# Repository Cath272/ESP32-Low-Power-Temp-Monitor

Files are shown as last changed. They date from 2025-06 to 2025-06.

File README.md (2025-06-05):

# ESP32 Low Power Temp Monitor

## Introduction
ESP32 Low Power Temp Monitor is an ESP32 C6 based low power Temperature and Humidity Monitor that aims to have a device that is very efficent and doen't need charging.
## General description
The device reads the temperature, relative humidity and barometric pressure  and displays it on an 4.2 inch Epaper Display, alonside the current date and time.
The device is awake just for a few seconds as it reads the tempereature and displays it and then goes to sleep. It performs a reading every minute.
One a day it connects to WiFi and checks the current time to sync up with an NTP server to account for Daylight saving time and potential drifts in the internal esp32 real time clock.

In the project files you may find ESP32-C3 instead of ESP32-C6. I named it wrong when i created the project. The issue is just the file names, the footprints are correct and use a C6.
The TPL5111 is currenly does not work properly so i emulated it in software using the esp32 deep sleep.

### Block diagram
block diagram

## Hardware Design
### ESP32 C6 Wroom 1 Module
This project is based around a ESP32 C6 Wroom 1 Module that incorporates a RISC-V single-core microprocessor with 4MB of flash, WiFi 6 and Zigbee
### TPS63020
The TPS63020 is High Efficiency Single Inductor Buck-Boost Converter, used for  converting the 5v from usb or the Li-ion battery voltage(3.0v to 4.2v) to a very stable 3.3V for the Microcontroller and the epaper display. The main advantage of this ic is its low operating quiescent current: 25 μA; and it's low cost:0.55€
### BME280
The BME280 is a digital humidity, pressure and temperature sensor.
### 4.2 Inch Epaper Display 
GDEY042Z98 Tri color (Black, White and Red) Epaper display using a SSD1683 driver chip, the main benefit of this display is its big size (4.2 inch) and very good price for an Epaper display (around 10€)
### TPL5111
The TPL5111 is a Nano Power System timer for power gating. It is used to turn on the esp32 every minute to read the temperature
### MCP7381
The MCP7381 is an integrated Li-ion cell battery controller 
### Li-ion 250MAh battery
Small 250Mah generic Li-ion cell with protection, used because of its small size
### Solar Panel
Generic 1W 5V Solar panel 

## Schematic
[Schematic](PCB/ESP32%20%20C3%20Zigbee%20Temp/ESP32%20%20C3%20Zigbee%20Temp.pdf)
## Bill of Materials

| Component | Image | Model  | Pcs | Price | 
| --- | ---  | ---  | --- | --- |
| ESP32-C6-WROOM-1-N8  |  Esp32 c6 | ESP32-C6-WROOM-1-N8 | 1 | € 4.91 |
|Buck Boost Coverter  |  | TPS63020 | 1 | € 0.52 | 
| TPL5111 | images | TPL5111 | 1 | € 0.47 | 
| BME280 | images | BME280 | 1 | € 2.78 |
| MCP7381 | images | MCP7381 | 1 | € 0.84 |
| Solar Panel | images | 5V 1W Solar Panel | 1 | € 2.23 |
| 4.2 Inch Epaper Display | images | GDEY042Z98 | 1 | € 11.64 |

## PCB

front_3d
front

## Case and 3d design

The case was make using autocad and exported to stl
The stl files can be found in the 3D Parts folder

The gerber production zip file can be found in the Production folder
## Software Design

The device wakes up, connect to wifi on the first boot, reads the time from an NTP server, and then for the next 24 hours it just reads the temperature and displays it. The time is kept in a register while the esp sleeps and increments it on every boot. Every 24 hours it connect to Wifi to check the time again for accuracy.
The program can be found in the Project_Code folder

### Display
The program is based around the [GxEPD2](https://github.com/ZinggJM/GxEPD2) libary for interfacing with the Epaper display,   

### Fonts
The font used in this project is Roboto with 2 diffrent font sizes: 16pt for the time, date, altitude and barometric pressure and 48pt for the Temeprature and relative humidity
The font were converted from True Type to Adafruit's GFX Font format (also used by GxEPD2 as it is based on Adafruit GFX) using the [ttf2gfx utility](https://github.com/Pconti31/TTF2GFX)

### BME280
Adafruit_BME280 for the BME280 sensor
### Time 
For time i used 4 libraries: 
- esp_timer (esp_idf library) to get the execution time of the code 
- [ESP32Time](https://github.com/fbiego/ESP32Time) for keeeping the time and displaying it in a C style format on the display
- [ezTime](https://github.com/ropg/ezTime) for getting the time from an NTP server, the time is region based in this library and i used it to avoid the problem of keeping track of daylight savings

## Results



## Resources
- [ESP32Time](https://github.com/fbiego/ESP32Time)
- [ttf2gfx utility](https://github.com/Pconti31/TTF2GFX)
- [ezTime](https://github.com/ropg/ezTime)
- [GxEPD2](https://github.com/ZinggJM/GxEPD2)

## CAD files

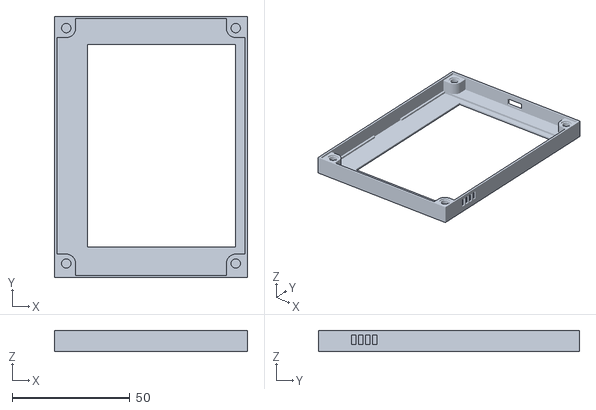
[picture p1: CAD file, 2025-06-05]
3dParts/front32.stl
82.0 x 111.0 x 9.00

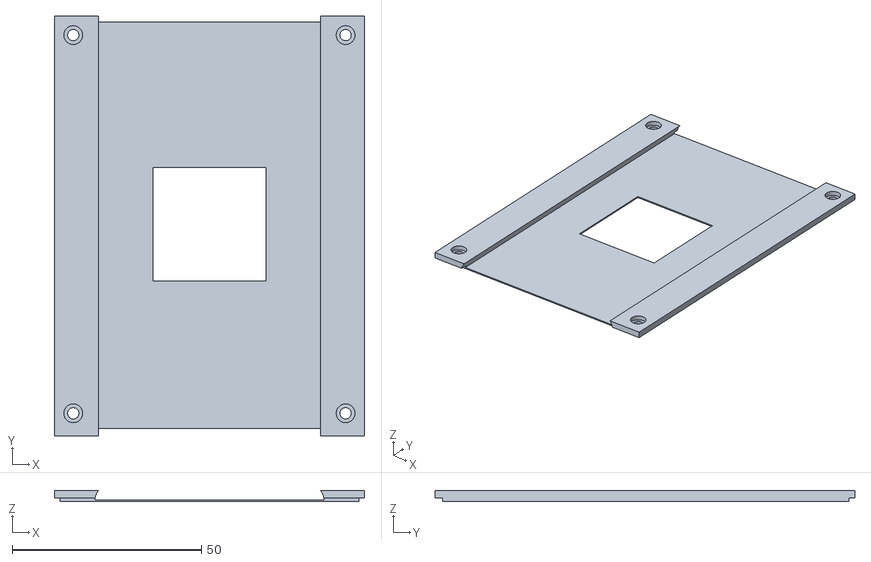
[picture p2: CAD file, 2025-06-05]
3dParts/back32.stl
82.0 x 111.0 x 3.00

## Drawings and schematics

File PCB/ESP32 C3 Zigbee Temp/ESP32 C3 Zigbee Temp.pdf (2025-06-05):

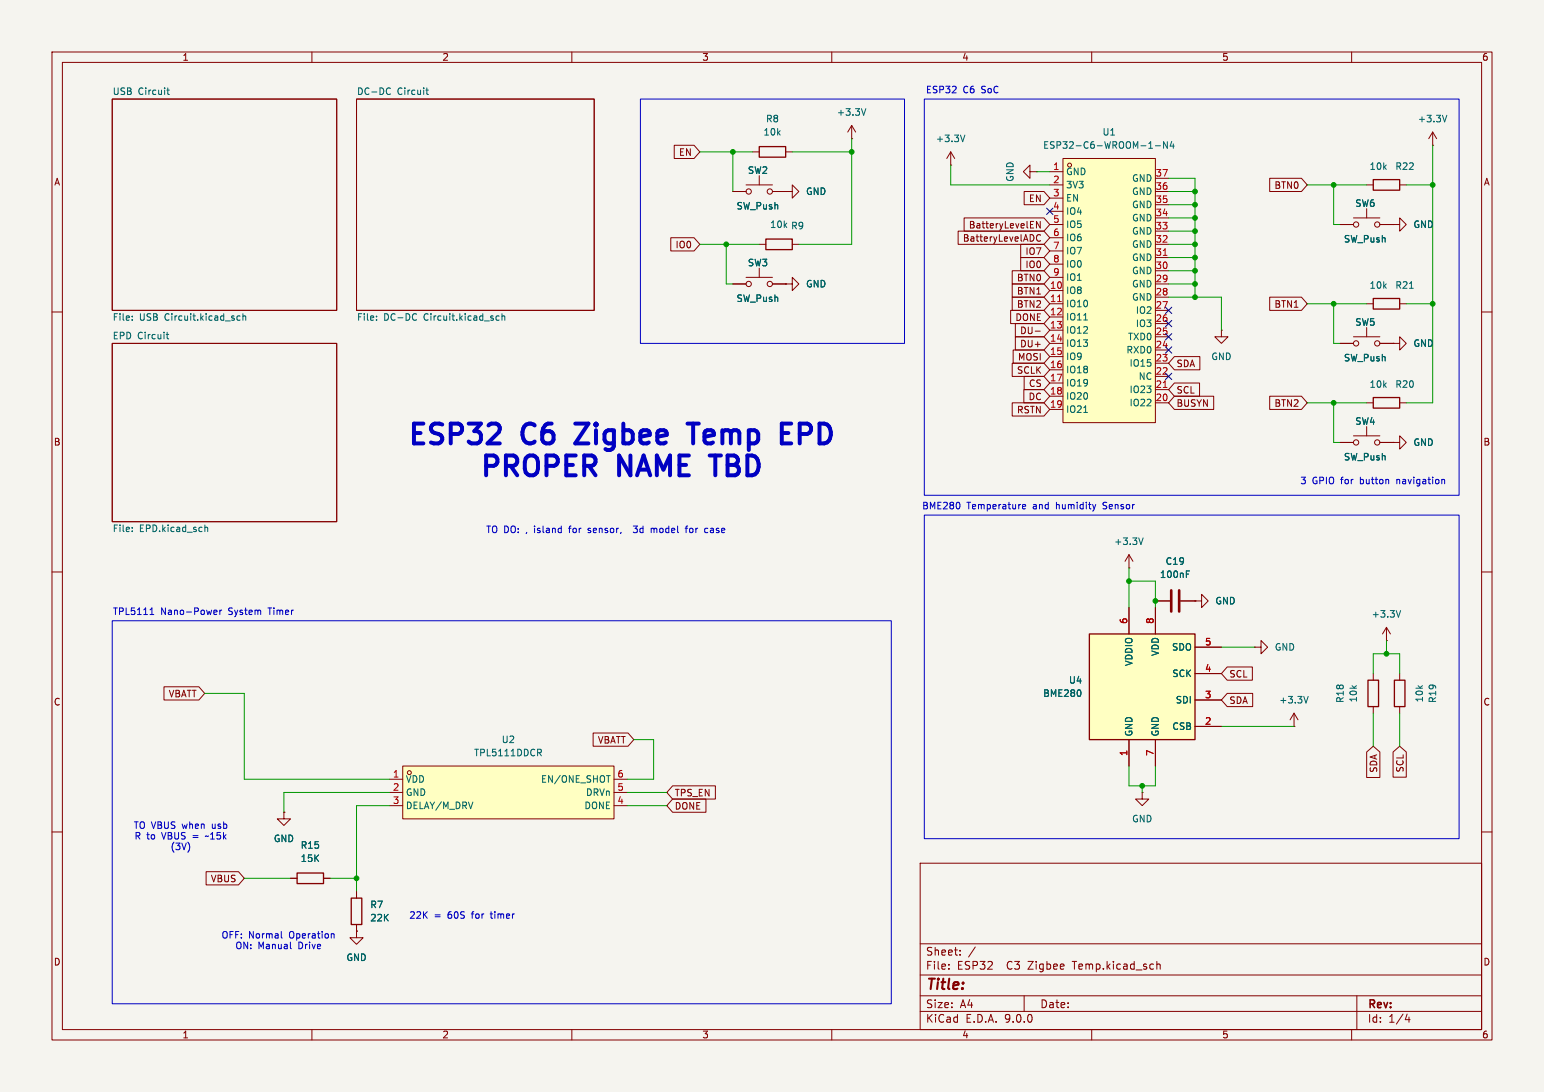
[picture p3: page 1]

7 SDO 5 SCK 4 SDI 3 CSB 2 U4 BME280 +3.3V GND GND

7 SDO 5 SCK 4 SDI 3 CSB 2 C19

OFF: Normal Operation ON: Manual Drive

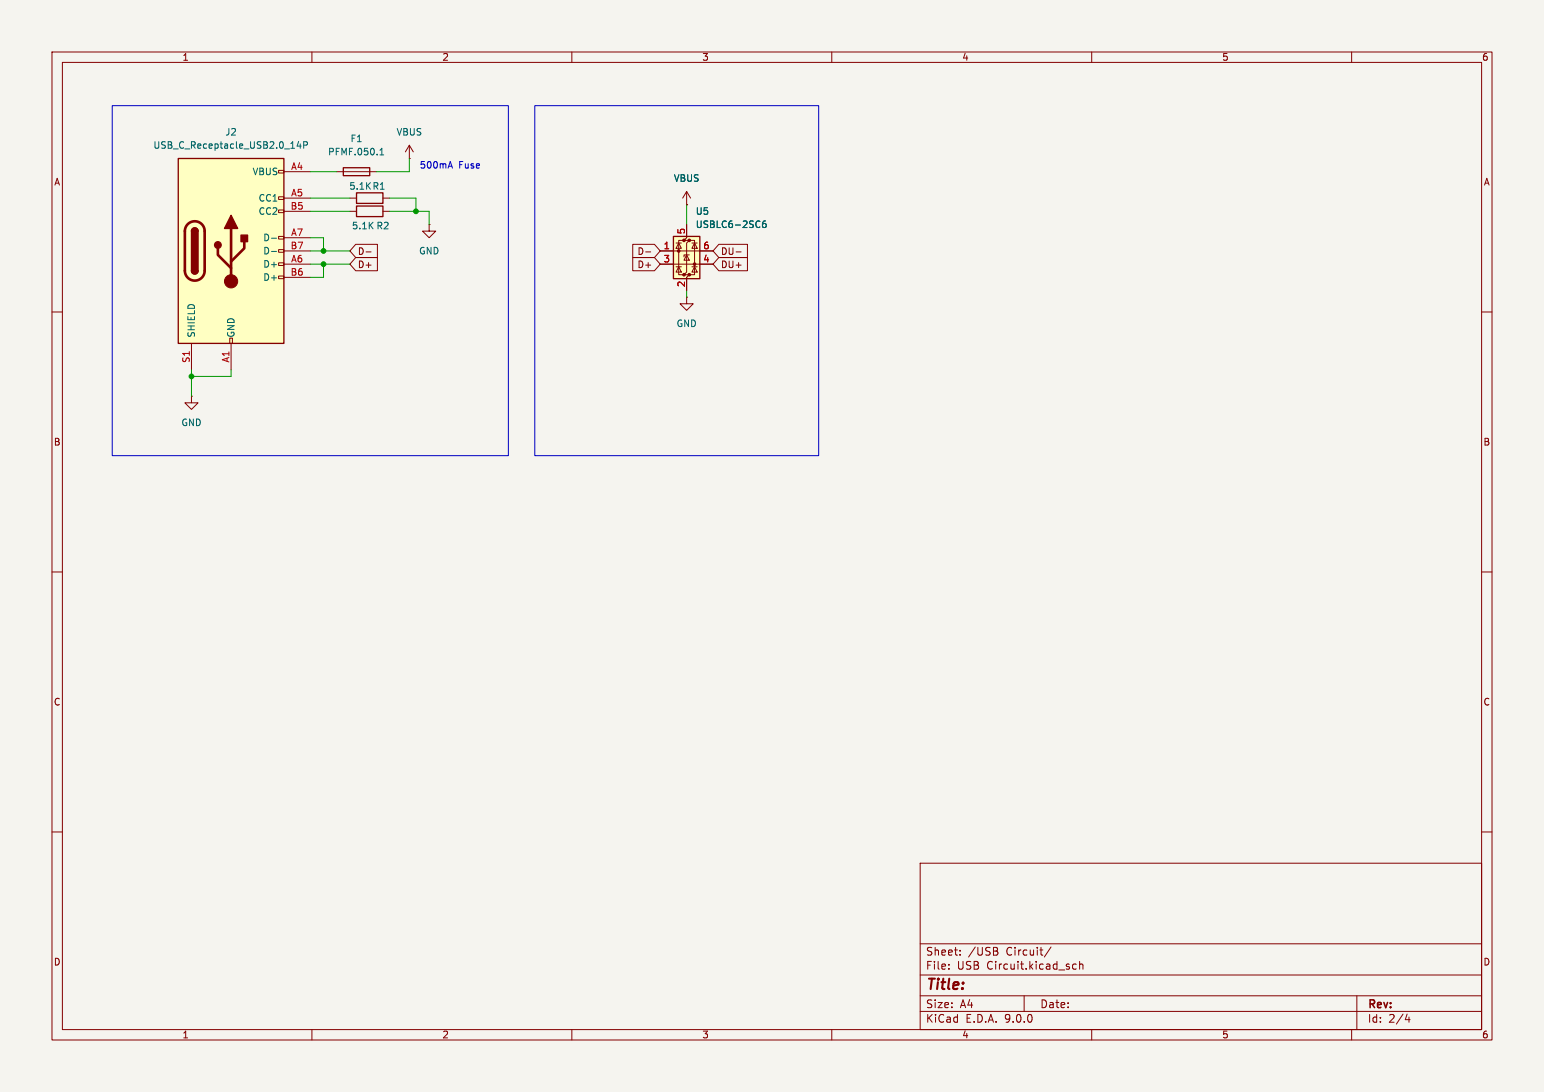
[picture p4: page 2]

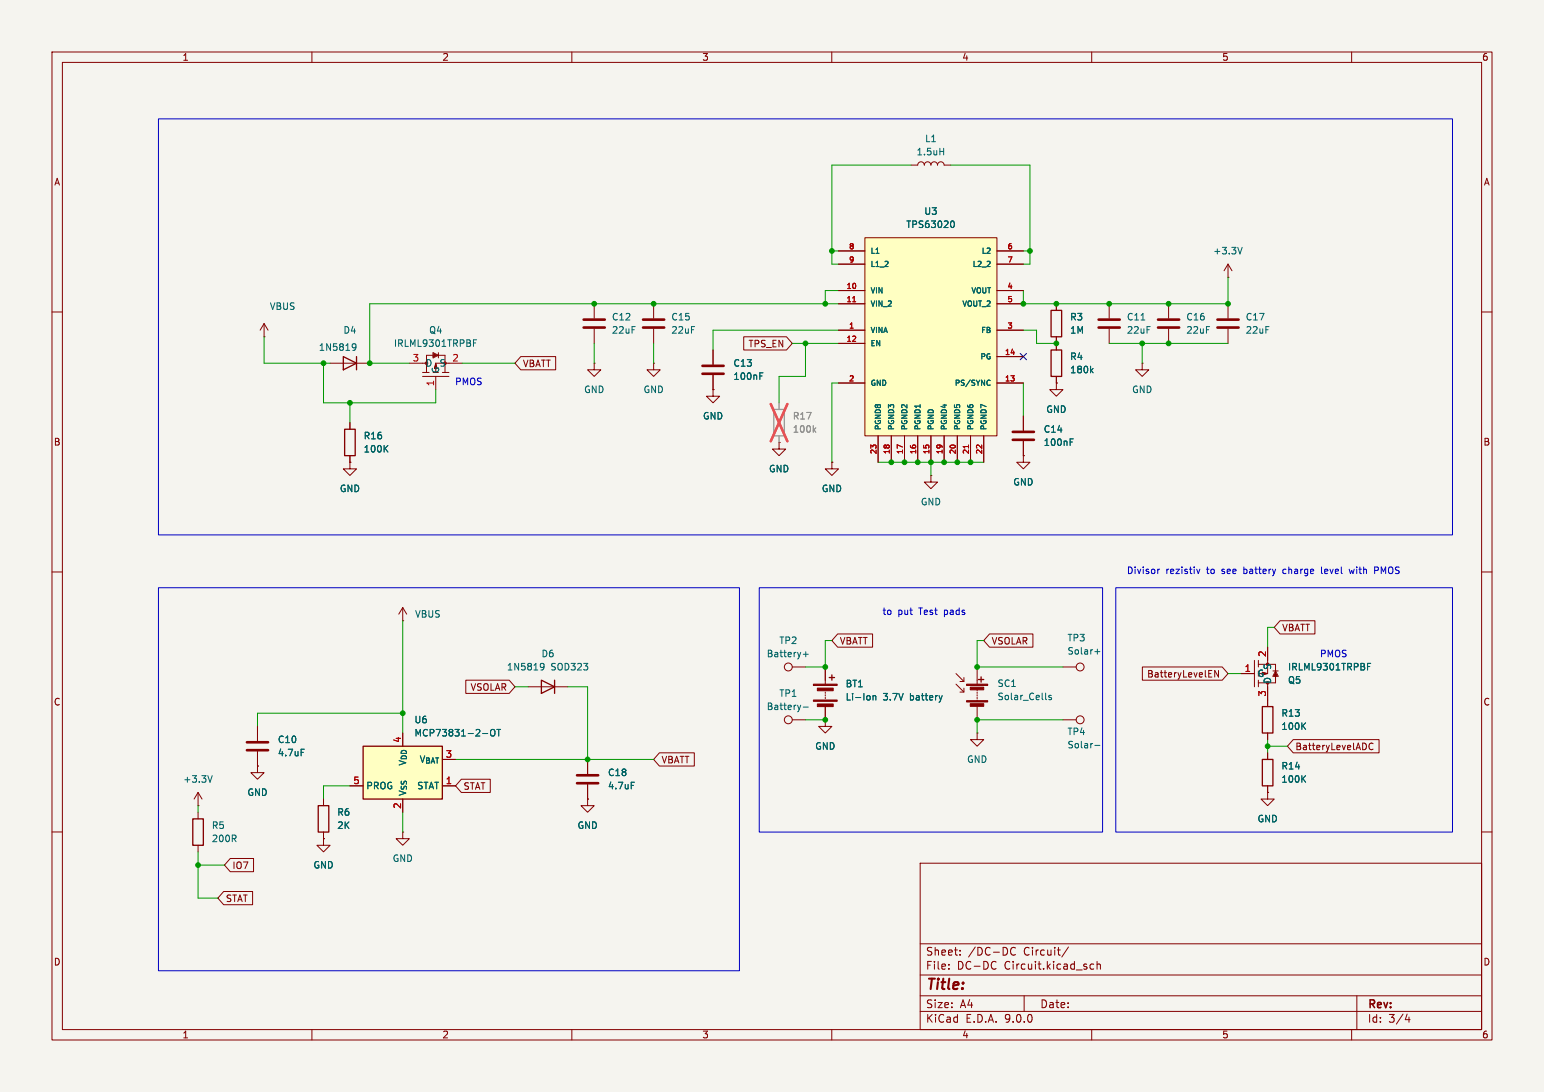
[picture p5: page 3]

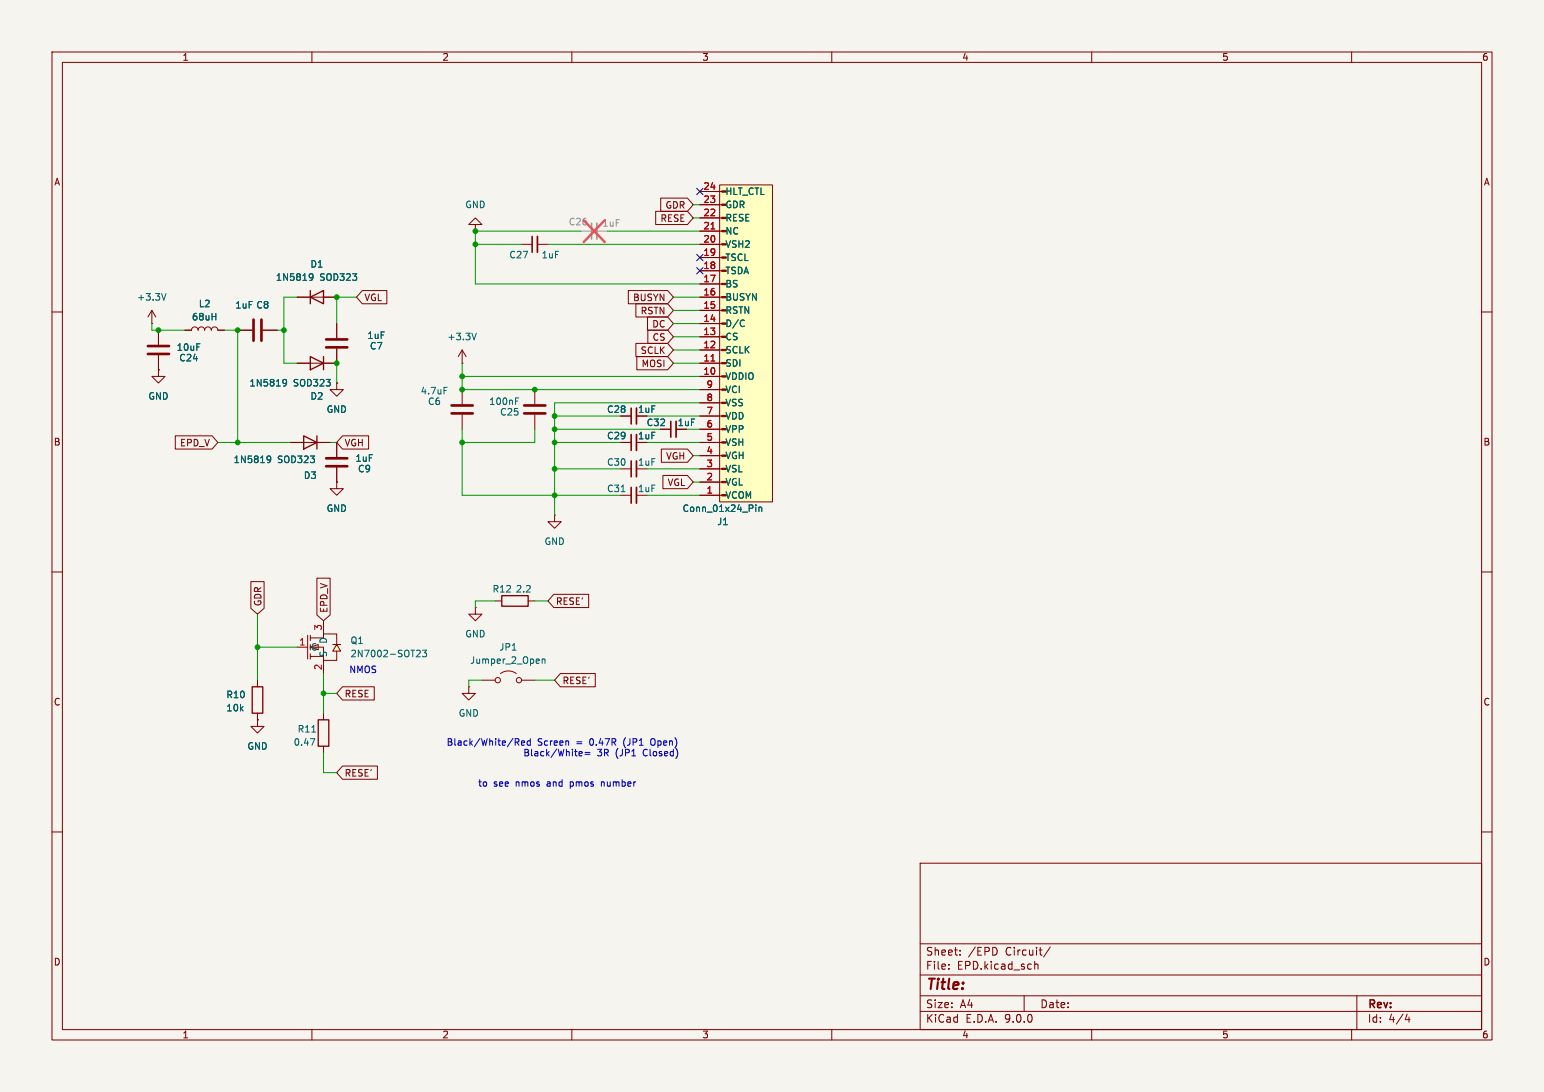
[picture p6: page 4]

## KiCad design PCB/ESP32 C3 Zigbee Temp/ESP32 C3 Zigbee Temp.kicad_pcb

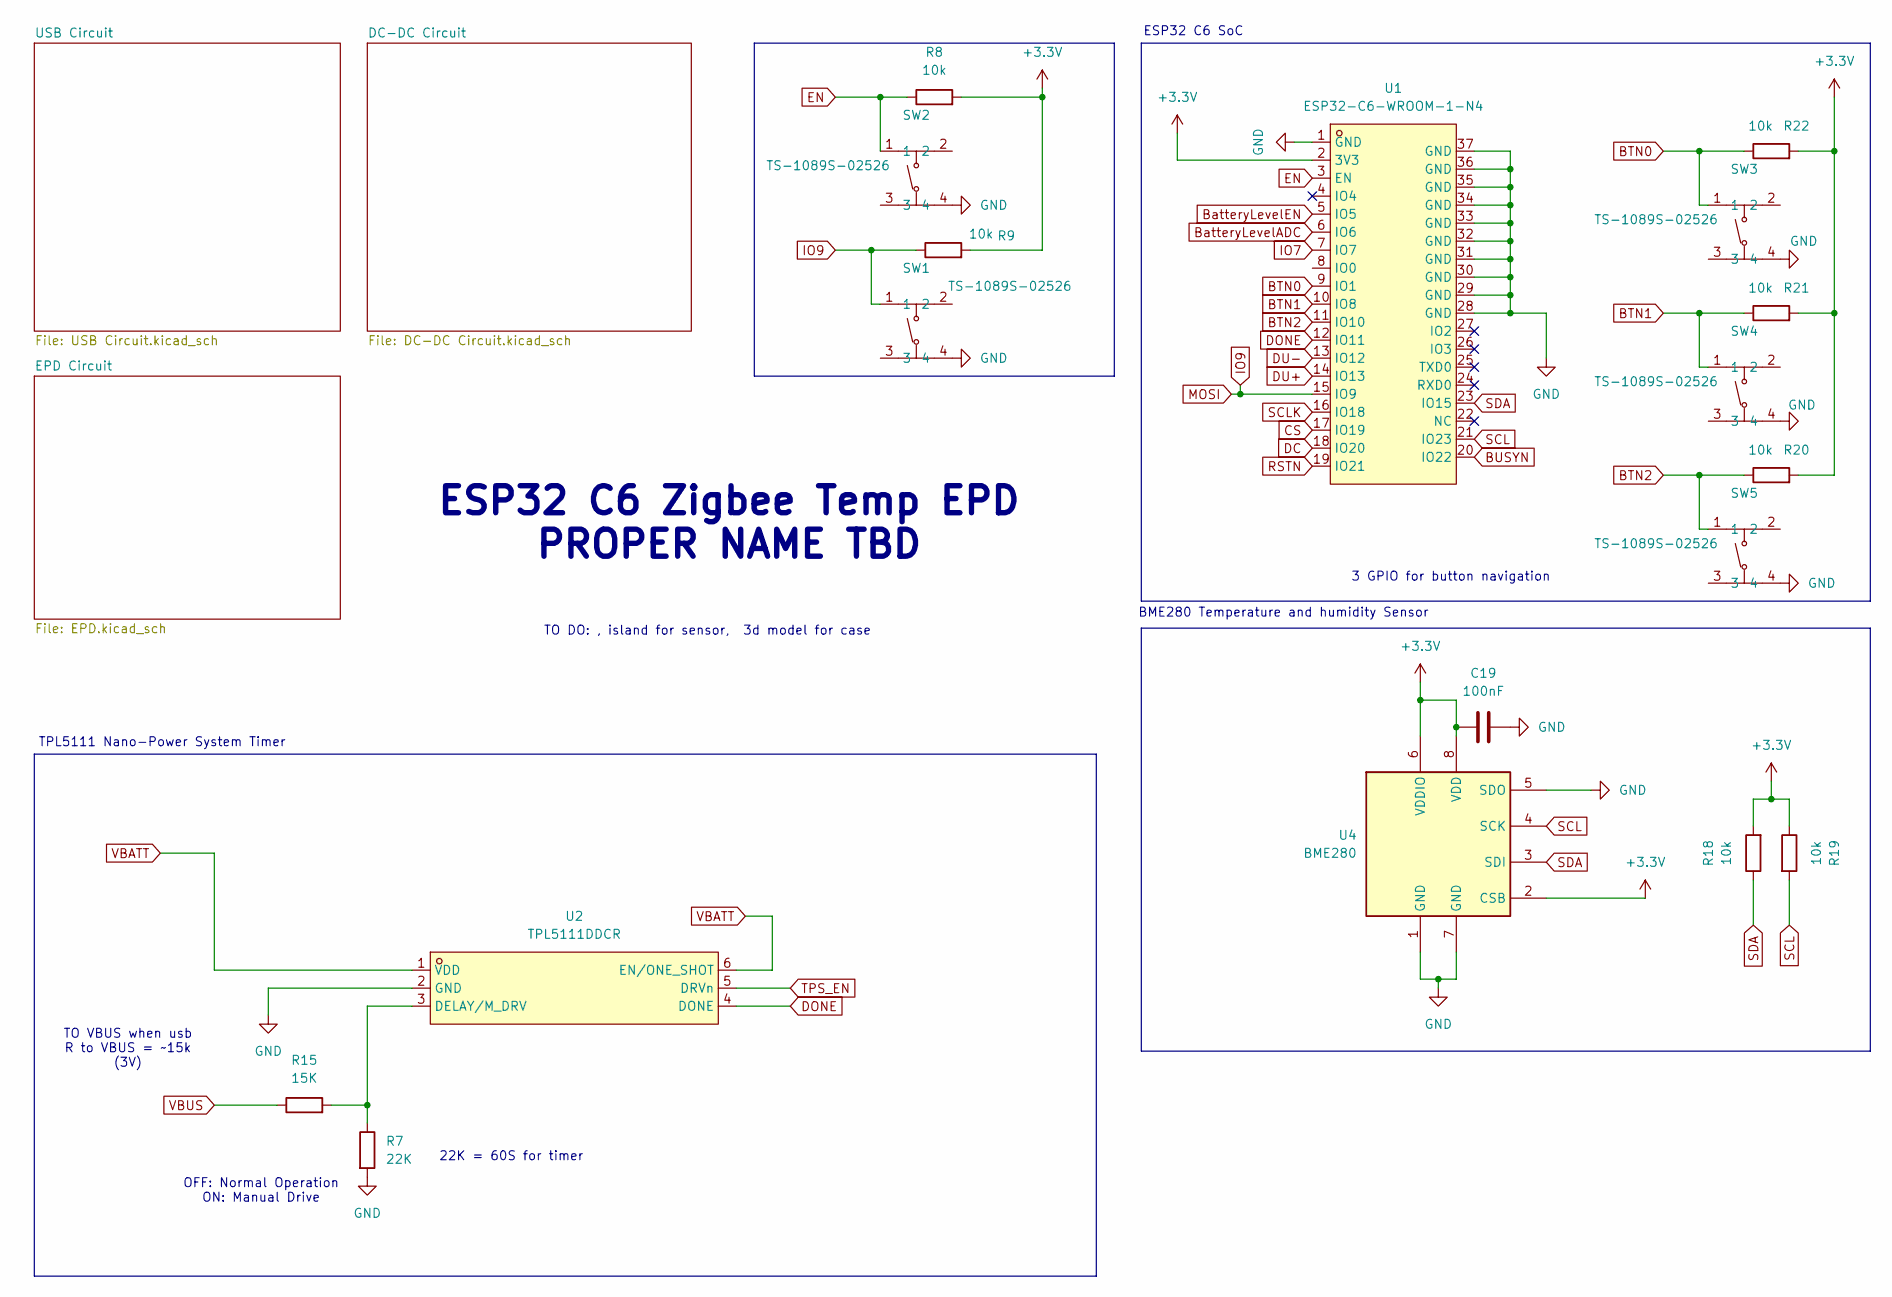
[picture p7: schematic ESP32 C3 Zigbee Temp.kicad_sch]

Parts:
C19: 100nF; C_0402_1005Metric
R7: 22K; R_0402_1005Metric
R8, R9, R18, R19, R20, R21, R22: 10k; R_0402_1005Metric
R15: 15K; R_0402_1005Metric
SW1, SW2, SW3, SW4, SW5: TS-1089S-02526; SW-SMD_4P-L4.2-W3.3-P2.15-LS5.1; LCSC Part C455282
U1: ESP32-C6-WROOM-1-N4; WIRELM-SMD_ESP32-C6-WROOM-1; LCSC Part C6034714
U2: TPL5111DDCR; TSOT-23-6_L2.9-W1.6-P0.95-LS2.8-BL; LCSC Part C2870554
U4: BME280; Bosch_LGA-8_2.5x2.5mm_P0.65mm_ClockwisePinNumbering

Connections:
+3.3V: C19.1, R8.2, R9.2, R18.2, R19.1, R20.2, R21.2, R22.2, U1.2 (3V3), U4.2 (CSB), U4.6 (VDDIO), U4.8 (VDD); also elsewhere on the board
BTN0: R22.1, SW3.1, U1.9 (IO1)
BTN1: R21.1, SW4.1, U1.10 (IO8)
BTN2: R20.1, SW5.1, U1.11 (IO10)
BUSYN: U1.20 (IO22); also elsewhere on the board
BatteryLevelADC: U1.6 (IO6); also elsewhere on the board
BatteryLevelEN: U1.5 (IO5); also elsewhere on the board
CS: U1.17 (IO19); also elsewhere on the board
DC: U1.18 (IO20); also elsewhere on the board
DONE: U1.12 (IO11), U2.4 (DONE)
DU+: U1.14 (IO13); also elsewhere on the board
DU-: U1.13 (IO12); also elsewhere on the board
EN: R8.1, SW2.1, U1.3 (EN)
GND: C19.2, R7.2, SW1.4, SW2.4, SW3.4, SW4.4, SW5.4, U1.1 (GND), U1.28 (GND), U1.29 (GND), U1.30 (GND), U1.31 (GND), U1.32 (GND), U1.33 (GND), U1.34 (GND), U1.35 (GND), U1.36 (GND), U1.37 (GND), U2.2 (GND), U4.1 (GND), U4.5 (SDO), U4.7 (GND); also elsewhere on the board
IO7: U1.7 (IO7); also elsewhere on the board
IO9: R9.1, SW1.1, U1.15 (IO9); also elsewhere on the board
unnamed: R7.1, R15.2, U2.3 (DELAY/M_DRV)
RSTN: U1.19 (IO21); also elsewhere on the board
SCL: R19.2, U1.21 (IO23), U4.4 (SCK)
SCLK: U1.16 (IO18); also elsewhere on the board
SDA: R18.1, U1.23 (IO15), U4.3 (SDI)
TPS_EN: U2.5 (DRVn); also elsewhere on the board
VBATT: U2.1 (VDD), U2.6 (EN/ONE_SHOT); also elsewhere on the board
VBUS: R15.1; also elsewhere on the board

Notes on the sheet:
ESP32 C6 SoC
OFF: Normal Operation ON: Manual Drive
3 GPIO for button navigation
TO DO: , island for sensor, 3d model for case
TO VBUS when usb R to VBUS = ~15k (3V)
TPL5111 Nano-Power System Timer
ESP32 C6 Zigbee Temp EPD PROPER NAME TBD
22K = 60S for timer
BME280 Temperature and humidity Sensor

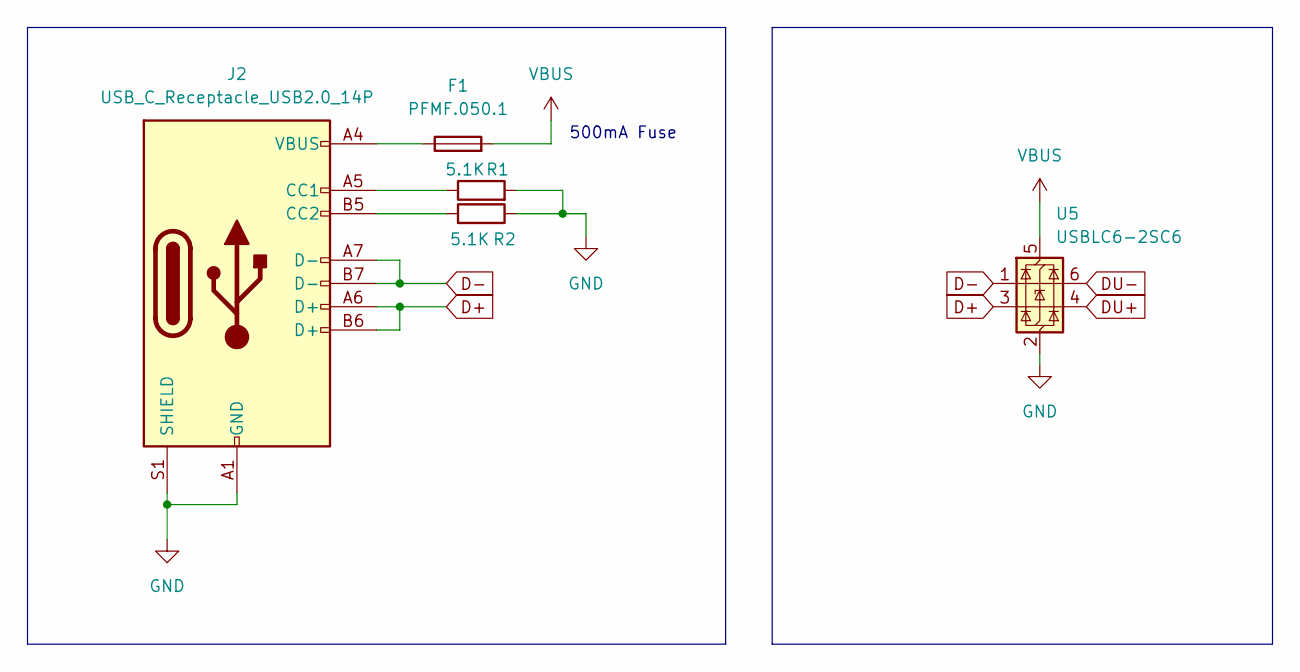
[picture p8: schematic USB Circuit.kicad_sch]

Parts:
F1: PFMF.050.1; Fuse_1812_4532Metric
J2: USB_C_Receptacle_USB2.0_14P; USB_C_Receptacle_GCT_USB4110
R1, R2: 5.1K; R_0402_1005Metric
U5: USBLC6-2SC6; SOT-23-6

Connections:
D+: J2.A6 (D+), J2.B6 (D+), U5.3 (I/O2)
D-: J2.A7 (D-), J2.B7 (D-), U5.1 (I/O1)
DU+: U5.4 (I/O2); also elsewhere on the board
DU-: U5.6 (I/O1); also elsewhere on the board
GND: J2.A1 (GND), J2.A12 (GND), J2.B1 (GND), J2.B12 (GND), J2.S1 (SHIELD), R1.2, R2.1, U5.2 (GND); also elsewhere on the board
unnamed: F1.1, J2.A4 (VBUS), J2.A9 (VBUS), J2.B4 (VBUS), J2.B9 (VBUS)
unnamed: J2.A5 (CC1), R1.1
unnamed: J2.B5 (CC2), R2.2
VBUS: F1.2, U5.5 (VBUS); also elsewhere on the board

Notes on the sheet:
500mA Fuse

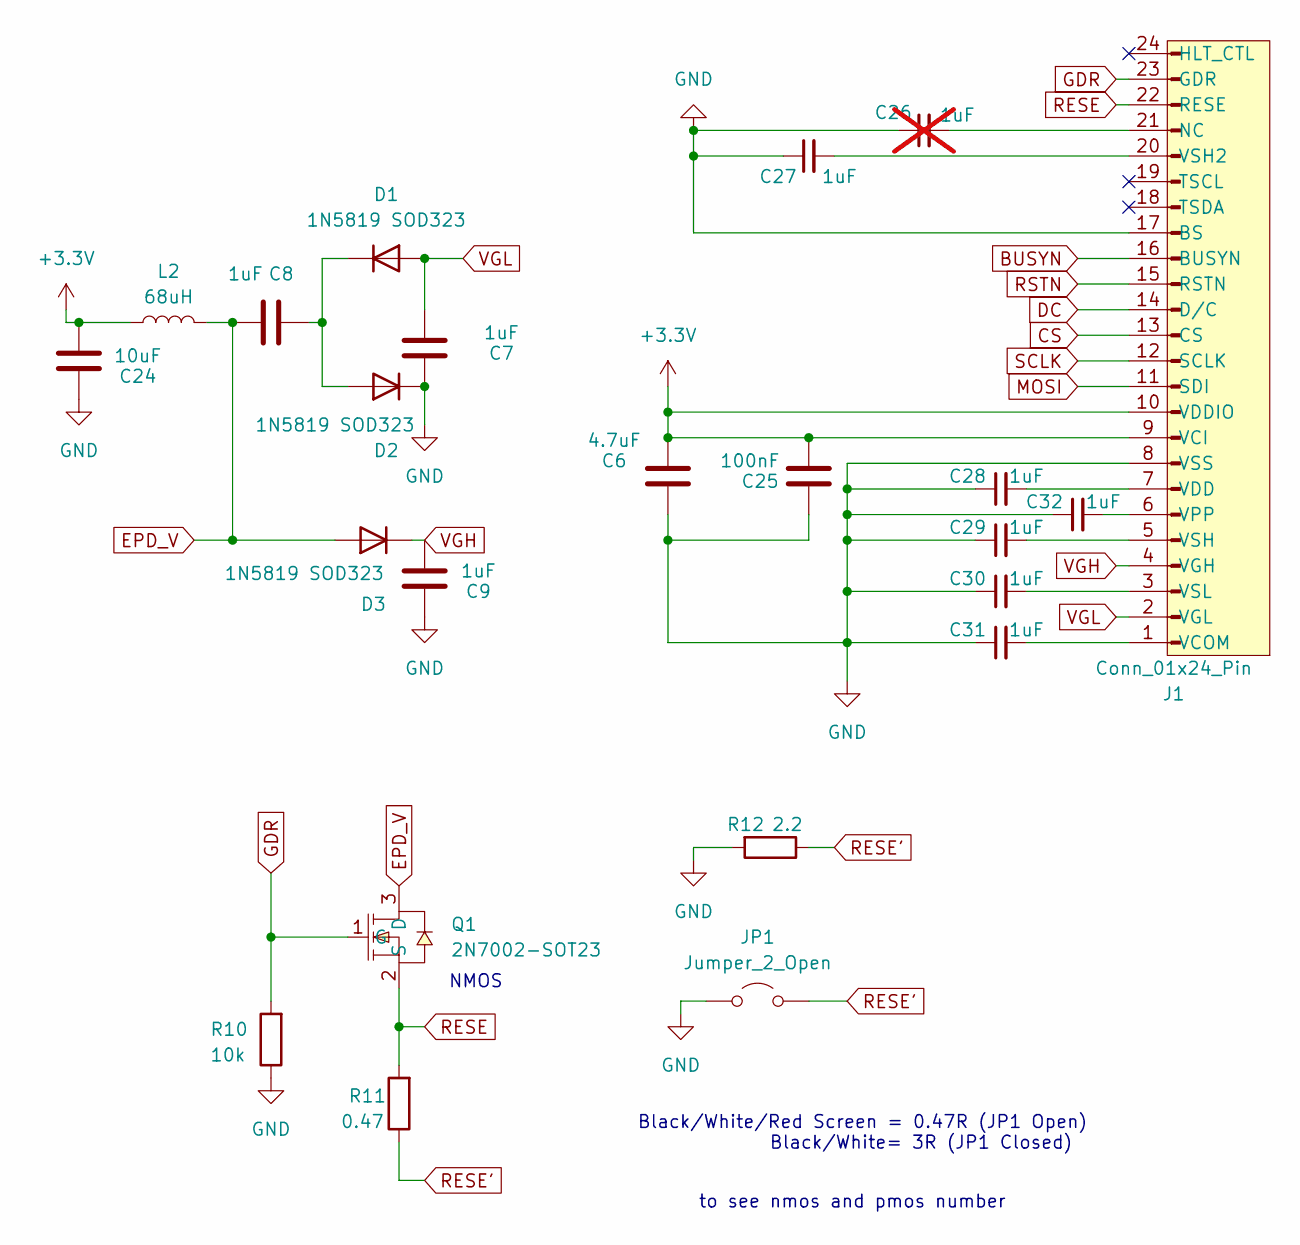
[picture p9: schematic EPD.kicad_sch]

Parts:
C6: 4.7uF; C_0805_2012Metric
C7, C8, C9, C27, C28, C29, C30, C31, C32: 1uF; C_0603_1608Metric
C24: 10uF; C_0805_2012Metric
C25: 100nF; C_0402_1005Metric
C26: 1uF; C_0603_1608Metric; not fitted
D1, D2, D3: 1N5819 SOD323; D_SOD-323
J1: Conn_01x24_Pin; MOLEX_5034802400
JP1: Jumper_2_Open; SolderJumper-2_P1.3mm_Open_TrianglePad1.0x1.5mm
L2: 68uH; L_APV_ANR4030
Q1: 2N7002-SOT23; SOT-23_L2.9-W1.3-P1.90-LS2.4-BR; LCSC Part C332103
R10: 10k; R_0402_1005Metric
R11: 0.47; R_0402_1005Metric
R12: 2.2; R_0402_1005Metric

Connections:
+3.3V: C6.2, C24.2, C25.2, J1.9 (VCI), J1.10 (VDDIO), L2.1; also elsewhere on the board
BUSYN: J1.16 (BUSYN); also elsewhere on the board
CS: J1.13 (CS); also elsewhere on the board
DC: J1.14 (D/C); also elsewhere on the board
EPD_V: C8.2, D3.2 (A), L2.2, Q1.3 (D)
GDR: J1.23 (GDR), Q1.1 (G), R10.2
GND: C6.1, C7.1, C9.1, C24.1, C25.1, C26.1, C27.1, C28.1, C29.1, C30.1, C31.1, C32.1, D2.1 (K), J1.8 (VSS), J1.17 (BS), JP1.1 (A), R10.1, R12.2; also elsewhere on the board
IO9: J1.11 (SDI); also elsewhere on the board
unnamed: C8.1, D1.1 (K), D2.2 (A)
unnamed: C26.2, J1.21 (NC)
unnamed: C31.2, J1.1 (VCOM)
unnamed: C28.2, J1.7 (VDD)
unnamed: C32.2, J1.6 (VPP)
unnamed: C27.2, J1.20 (VSH2)
unnamed: C29.2, J1.5 (VSH)
unnamed: C30.2, J1.3 (VSL)
RESE: J1.22 (RESE), Q1.2 (S), R11.2
RESE': JP1.2 (B), R11.1, R12.1
RSTN: J1.15 (RSTN); also elsewhere on the board
SCLK: J1.12 (SCLK); also elsewhere on the board
VGH: C9.2, D3.1 (K), J1.4 (VGH)
VGL: C7.2, D1.2 (A), J1.2 (VGL)

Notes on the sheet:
to see nmos and pmos number
NMOS
Black/White/Red Screen = 0.47R (JP1 Open) Black/White= 3R (JP1 Closed)

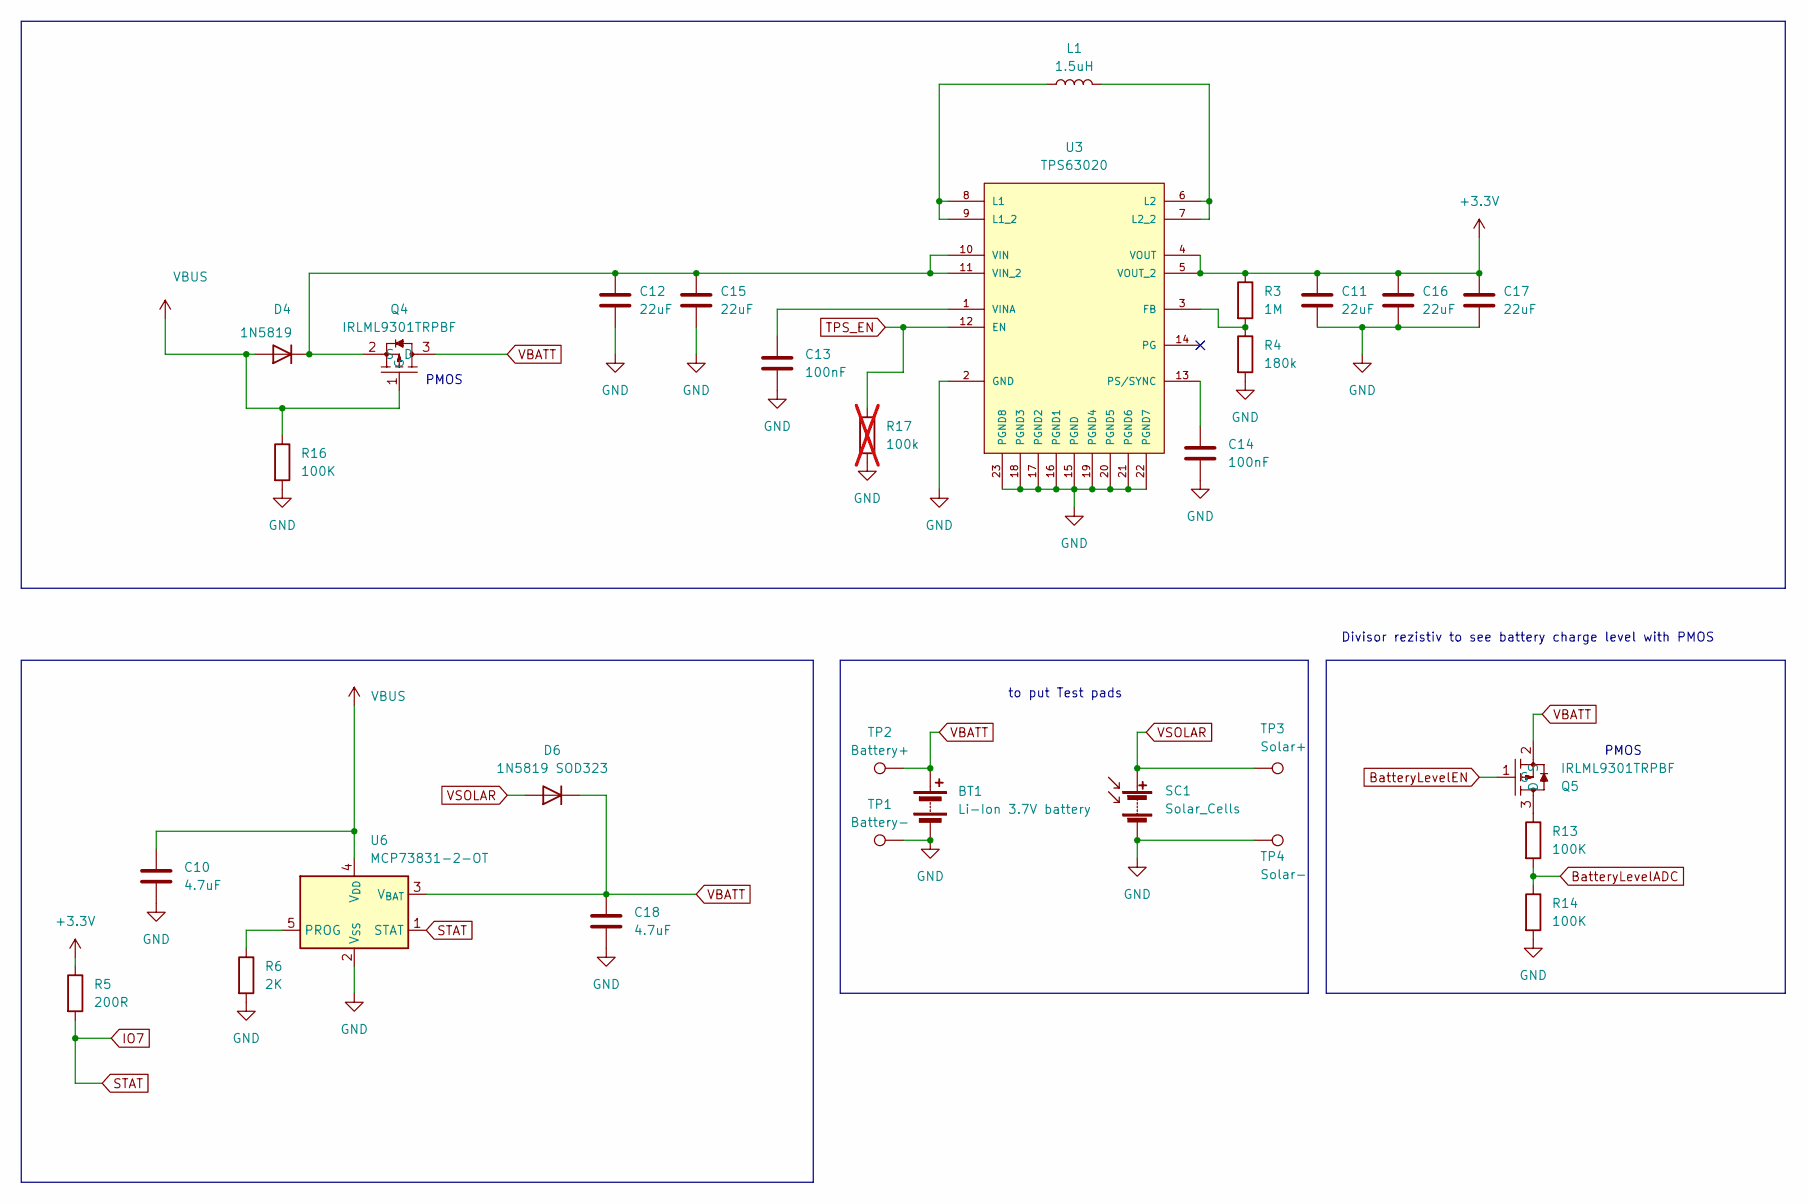
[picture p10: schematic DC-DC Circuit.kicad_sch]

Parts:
BT1: Li-Ion 3.7V battery
C10, C18: 4.7uF; C_0805_2012Metric
C11, C12, C15, C16, C17: 22uF; C_0805_2012Metric
C13, C14: 100nF; C_0402_1005Metric
D4: 1N5819; D_SOD-323
D6: 1N5819 SOD323; D_SOD-323
L1: 1.5uH; L_APV_ANR4030
Q4, Q5: IRLML9301TRPBF; SOT-23_L2.9-W1.3-P1.90-LS2.4-BR; LCSC Part C82056
R3: 1M; R_0402_1005Metric
R4: 180k; R_0402_1005Metric
R5: 200R; R_0402_1005Metric
R6: 2K; R_0402_1005Metric
R13, R14, R16: 100K; R_0402_1005Metric
R17: 100k; R_0402_1005Metric; not fitted
SC1: Solar_Cells
TP1: Battery-; TestPoint_Pad_2.0x2.0mm
TP2: Battery+; TestPoint_Pad_2.0x2.0mm
TP3: Solar+; TestPoint_Pad_2.0x2.0mm
TP4: Solar-; TestPoint_Pad_2.0x2.0mm
U3: TPS63020; VSON-14_L4.0-W3.0-P0.50-BL-EP_TI_DSJ
U6: MCP73831-2-OT; SOT-23-5

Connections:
+3.3V: C11.1, C16.1, C17.1, R3.1, R5.1, U3.4 (VOUT), U3.5 (VOUT_2); also elsewhere on the board
BatteryLevelADC: R13.2, R14.1; also elsewhere on the board
BatteryLevelEN: Q5.1 (G); also elsewhere on the board
GND: BT1.2 (-), C10.2, C11.2, C12.2, C13.2, C14.2, C15.2, C16.2, C17.2, C18.2, R4.2, R6.2, R14.2, R16.2, R17.2, SC1.2 (-), TP1.1, TP4.1, U3.2 (GND), U3.15 (PGND), U3.16 (PGND1), U3.17 (PGND2), U3.18 (PGND3), U3.19 (PGND4), U3.20 (PGND5), U3.21 (PGND6), U3.22 (PGND7), U3.23 (PGND8), U6.2 (V_{SS}); also elsewhere on the board
IO7: R5.2, U6.1 (STAT); also elsewhere on the board
unnamed: C12.1, C15.1, D4.1 (K), Q4.2 (S), U3.10 (VIN), U3.11 (VIN_2)
unnamed: Q5.3 (D), R13.1
unnamed: R3.2, R4.1, U3.3 (FB)
unnamed: L1.1, U3.8 (L1), U3.9 (L1_2)
unnamed: L1.2, U3.6 (L2), U3.7 (L2_2)
unnamed: C14.1, U3.13 (PS/SYNC)
unnamed: C13.1, U3.1 (VINA)
unnamed: R6.1, U6.5 (PROG)
TPS_EN: R17.1, U3.12 (EN); also elsewhere on the board
VBATT: BT1.1 (+), C18.1, D6.1 (K), Q4.3 (D), Q5.2 (S), TP2.1, U6.3 (V_{BAT}); also elsewhere on the board
VBUS: C10.1, D4.2 (A), Q4.1 (G), R16.1, U6.4 (V_{DD}); also elsewhere on the board
VSOLAR: D6.2 (A), SC1.1 (+), TP3.1

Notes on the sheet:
Divisor rezistiv to see battery charge level with PMOS
PMOS
to put Test pads
PMOS

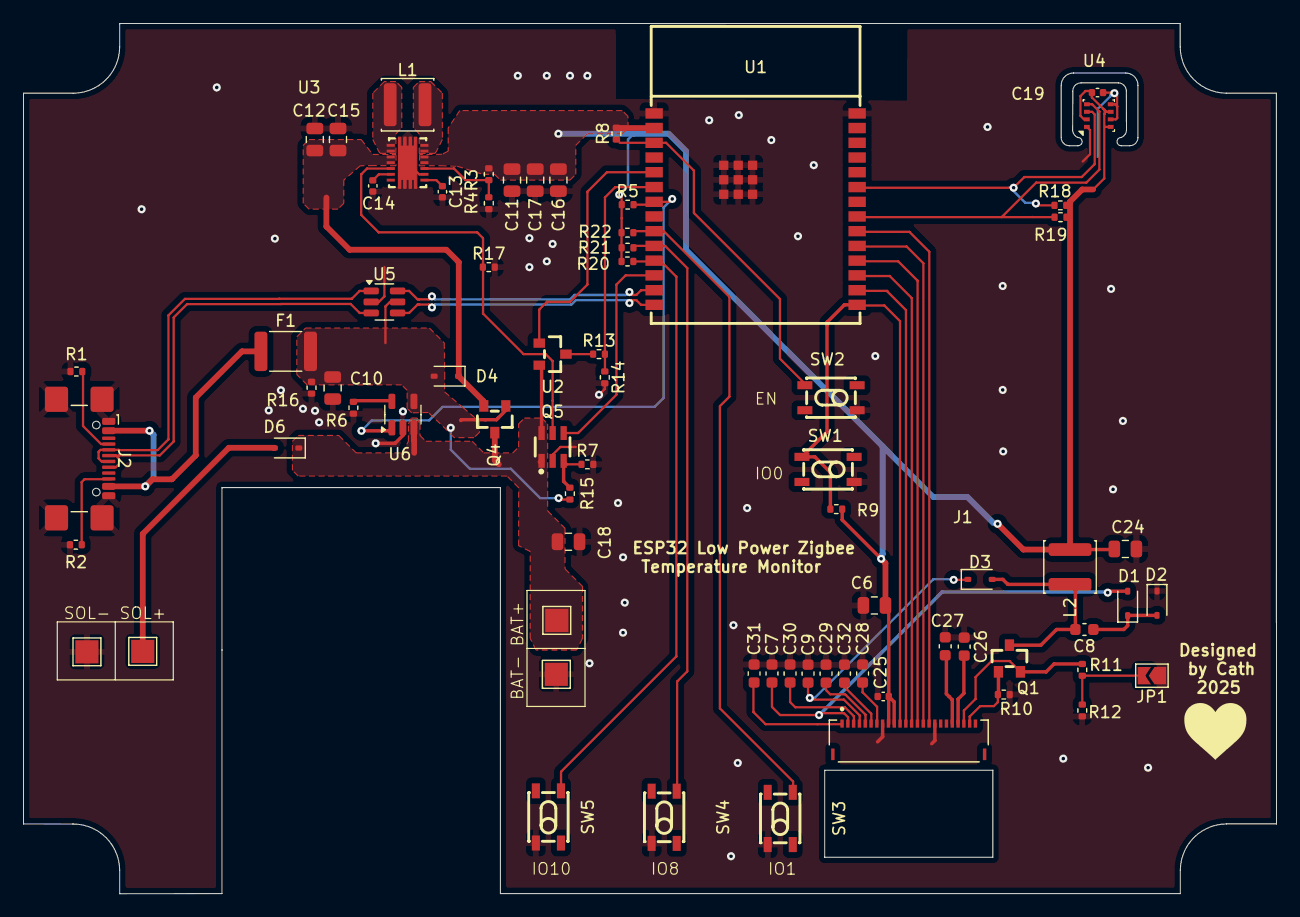
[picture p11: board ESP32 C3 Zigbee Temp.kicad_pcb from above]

Board: 2 copper layers, 108.0 x 75.0 mm, 74 parts (0 on the bottom side), 52 nets.

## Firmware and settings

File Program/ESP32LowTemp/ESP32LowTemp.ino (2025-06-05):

// Display Library example for SPI e-paper panels from Dalian Good Display and boards from Waveshare.
// Requires HW SPI and Adafruit_GFX. Caution: the e-paper panels require 3.3V supply AND data lines!
//
// Display Library based on Demo Example from Good Display: https://www.good-display.com/companyfile/32/
//
// Author: Jean-Marc Zingg
//
// Version: see library.properties
//
// Library: https://github.com/ZinggJM/GxEPD2
//
// Purpose: show uses of GxEPD2_GFX base class for references to a display instance

// Supporting Arduino Forum Topics (closed, read only):
// Good Display ePaper for Arduino: https://forum.arduino.cc/t/good-display-epaper-for-arduino/419657
// Waveshare e-paper displays with SPI: https://forum.arduino.cc/t/waveshare-e-paper-displays-with-spi/467865
//
// Add new topics in https://forum.arduino.cc/c/using-arduino/displays/23 for new questions and issues

// see GxEPD2_wiring_examples.h for wiring suggestions and examples

// base class GxEPD2_GFX can be used to pass references or pointers to the display instance as parameter, uses ~1.2k more code
// enable GxEPD2_GFX base class
#define ENABLE_GxEPD2_GFX 1

// uncomment next line to use class GFX of library GFX_Root instead of Adafruit_GFX
//#include <GFX.h>
// Note: if you use this with ENABLE_GxEPD2_GFX 1:
//       uncomment it in GxEPD2_GFX.h too, or add #include <GFX.h> before any #include <GxEPD2_GFX.h>
// !!!!  ============================================================================================ !!!!

const unsigned char wifiIcon [] PROGMEM = {
	0x00, 0x00, 0x00, 0x00, 0x00, 0x00, 0x00, 0x00, 0x00, 0x00, 0x00, 0x03, 0xff, 0xc0, 0x00, 0x00, 
	0x1f, 0xff, 0xf8, 0x00, 0x00, 0xff, 0xff, 0xfe, 0x00, 0x01, 0xfc, 0x00, 0x7f, 0x80, 0x07, 0xe0, 
	0x00, 0x0f, 0xc0, 0x0f, 0x80, 0x00, 0x03, 0xe0, 0x1f, 0x00, 0x00, 0x00, 0xf8, 0x3c, 0x00, 0xff, 
	0x00, 0x78, 0x38, 0x07, 0xff, 0xe0, 0x38, 0x00, 0x1f, 0xff, 0xf8, 0x00, 0x00, 0x7f, 0x01, 0xfc, 
	0x00, 0x00, 0xfc, 0x00, 0x3e, 0x00, 0x01, 0xf0, 0x00, 0x0f, 0x00, 0x01, 0xe0, 0x00, 0x07, 0x00, 
	0x00, 0x80, 0x7c, 0x02, 0x00, 0x00, 0x01, 0xff, 0x80, 0x00, 0x00, 0x07, 0xff, 0xc0, 0x00, 0x00, 
	0x0f, 0xc3, 0xe0, 0x00, 0x00, 0x0f, 0x00, 0xe0, 0x00, 0x00, 0x06, 0x00, 0x40, 0x00, 0x00, 0x00, 
	0x00, 0x00, 0x00, 0x00, 0x00, 0x38, 0x00, 0x00, 0x00, 0x00, 0x7c, 0x00, 0x00, 0x00, 0x00, 0x7c, 
	0x00, 0x00, 0x00, 0x00, 0x7c, 0x00, 0x00, 0x00, 0x00, 0x7c, 0x00, 0x00, 0x00, 0x00, 0x38, 0x00, 
	0x00, 0x00, 0x00, 0x00, 0x00, 0x00, 0x00, 0x00, 0x00, 0x00, 0x00, 0x00, 0x00, 0x00, 0x00, 0x00
};


#include <GxEPD2_3C.h>
#include <Wire.h>
#include <SPI.h>
#include <Adafruit_Sensor.h>
#include "Adafruit_BME280.h"
#include <ESP32Time.h>
#include "esp_timer.h"

#include "BitmapDisplay.h"
#include "TextDisplay.h"
#include "Roboto_Regular16pt7b.h"
#include "roboto_regular48pt.h"

#include <ezTime.h>
#include <WiFi.h>

const char* ssid       = "UPB-Guest";
const char* password   = "";



// select the display constructor line in one of the following files (old style):
#include "GxEPD2_display_selection.h"


// for handling alternative SPI pins (ESP32, RP2040) see example GxEPD2_Example.ino


BitmapDisplay bitmaps(display);




#define SEALEVELPRESSURE_HPA (1013.25)

RTC_DATA_ATTR uint64_t boot_time_unix = 0;  // Unix timestamp
RTC_DATA_ATTR int boot_count = 0;

Adafruit_BME280 bme; // I2C

ESP32Time rtc;

int BatteryLevel;


void setup()
{
  Timezone RomaniaTime;
  
  Serial.begin(115200);
  boot_count++;

  pinMode(5, OUTPUT);
  digitalWrite(5, HIGH);
  
  Wire.setPins(15, 23);
  if (!bme.begin(0x76)) {
    Serial.println("Could not find a valid BME280 sensor, check wiring!");
    while (1);
  }

  // How long we've been asleep
  const uint64_t sleep_duration_us = 60 * 1000000ULL; // 60s
  const uint64_t sleep_duration_s = sleep_duration_us / 1000000ULL;

  // Update time
  if (boot_count == 1 || ((boot_count - 1) % 1440 == 0) ) {
    // First boot: assume an approximate start time (e.g., 0 or set manually)
    WiFi.begin(ssid);
    waitForSync();
    RomaniaTime.setLocation("RO");
    Serial.println("Getting Time fron NTP Server");
    Serial.print(RomaniaTime.dateTime());
    setInterval();
    boot_time_unix=RomaniaTime.now();
    rtc.setTime(boot_time_unix); 
    WiFi.disconnect();

  } else {
    boot_time_unix += sleep_duration_s;  // Advance stored Unix time
    rtc.setTime(boot_time_unix);         // Update RTC with estimated time
    Serial.println("Woke from deep sleep: updating RTC time.");
  }

 // Print the time (formatted and raw)
  Serial.print("Boot count: ");
  Serial.println(boot_count);

  Serial.print("RTC Time: ");
  Serial.println(rtc.getTime("%A, %B %d %Y %H:%M:%S"));  // Nice format

  Serial.print("Epoch Time: ");
  Serial.println(rtc.getEpoch());


  digitalWrite(5, LOW);
  BatteryLevel = analogRead(6);
  digitalWrite(5, HIGH);

  Serial.println();
  Serial.print("Battery adc: ");
  Serial.println(BatteryLevel);



  Serial.println("setup");

  
  SPI.begin(18, -1, 9, 19); // remap spi for EPD (swap pins), (sck, miso, mosi, ss)
 
  delay(100);
  display.init(115200); // default 10ms reset pulse, e.g. for bare panels with DESPI-C02
 
  Serial.println("setup done");

  // Your task
  showTemp();
  uint64_t end = esp_timer_get_time();
  
  // Go to deep sleep for 60 seconds
  Serial.println("Going to sleep for 60 seconds...");
  esp_sleep_enable_timer_wakeup(sleep_duration_us-end); // 60 seconds in microseconds
  Serial.flush(); // Wait for all serial output
  esp_deep_sleep_start();

   
   


}

void loop()
{
 
}


void showTemp(){

  
  Serial.print("Temperature = ");
  Serial.print(bme.readTemperature());
  Serial.println(" ˚C");

  Serial.print("Pressure = ");
  Serial.print(bme.readPressure() / 100.0F);
  Serial.println(" hPa");

  Serial.print("Approx. Altitude = ");
    Serial.print(bme.readAltitude(SEALEVELPRESSURE_HPA));
    Serial.println(" m");

  Serial.print("Humidity = ");
  Serial.print(bme.readHumidity());
  Serial.println(" %");

  Serial.println();

 
  display.setRotation(0);
  

  
  display.firstPage();

    display.setFont(&roboto_regular48pt);
    display.setTextColor(GxEPD_BLACK);
    int16_t tbx, tby; uint16_t tbw, tbh;
    // center text
    display.getTextBounds(String(bme.readTemperature() )+ "*C", 0, 0, &tbx, &tby, &tbw, &tbh);
    uint16_t wx = (display.width() - tbw) / 2;
    uint16_t wy = (display.height() / 3) + tbh / 2; // y is base line!
    display.getTextBounds(String(bme.readHumidity() )+ "%", 0, 0, &tbx, &tby, &tbw, &tbh);
    uint16_t fx = (display.width() - tbw) / 2;
    uint16_t fy = (display.height() * 2 / 3) + tbh / 2; // y is base line!
    

  
    //display.fillScreen(GxEPD_WHITE);
    display.setCursor(wx, wy);
    display.print(String(bme.readTemperature()));
    display.write(0x7F);
    display.print("C");
    display.setCursor(fx, fy);
    display.print(String(bme.readHumidity() )+ "%");


    display.setFont(&Roboto_Regular16pt7b);
    display.getTextBounds(rtc.getTime("%H:%M %a, %d %b"), 0, 0, &tbx, &tby, &tbw, &tbh);
    uint16_t rx = ( 10);
    uint16_t ry = (tbh + 5) ; // y is base line!

    display.setCursor(rx, ry);
    //display.print(rtc.getTime("%A, %B %d %Y %H:%M"));
    display.print(rtc.getTime("%H:%M %a, %d %b"));
    display.fillRect( display.width()-80, 10, 61, 35, GxEPD_BLACK );
    display.fillRect( display.width()-78, 12, 56, 30, GxEPD_WHITE);
    display.fillRect( display.width()-19, 18, 7, 20, GxEPD_BLACK );

    if(BatteryLevel >1750 && BatteryLevel <1874){
    display.fillRect( display.width()-76, 15, 16, 25, GxEPD_BLACK );

    }else if(BatteryLevel > 1875 && BatteryLevel <1949){
      display.fillRect( display.width()-76, 15, 16, 25, GxEPD_BLACK );
      display.fillRect( display.width()-58, 15, 16, 25, GxEPD_BLACK );
    }else if(BatteryLevel >1950){
      display.fillRect( display.width()-76, 15, 16, 25, GxEPD_BLACK );
      display.fillRect( display.width()-58, 15, 16, 25, GxEPD_BLACK );
      display.fillRect( display.width()-40, 15, 16, 25, GxEPD_BLACK );
    }
    
    
    display.drawBitmap(display.width()-130, 12, wifiIcon , 40, 32, GxEPD_BLACK);

    display.setCursor(10, display.height()-10);
    display.print(String(bme.readAltitude(SEALEVELPRESSURE_HPA) )+ "m");

    display.getTextBounds(String(bme.readPressure() / 100.0F )+ " hPa", 0, 0, &tbx, &tby, &tbw, &tbh);
    display.setCursor(display.width() - tbw - 10, display.height()-10);
    display.print(String(bme.readPressure() / 100.0F )+ " hPa");




  display.nextPage();

  
  

}
